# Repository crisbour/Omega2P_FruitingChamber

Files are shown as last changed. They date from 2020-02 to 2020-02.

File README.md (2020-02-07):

# Omega2P_FruitingChamber
Code for Omega2+ to control humidity, temperature, air flow and lights for an automated fruiting chamber to grow mushrooms.

Sensors:
- 2x D18B20 Temperature 1-Wire
- GY-BME280  Humidity + Temperature I<sup>2</sup>C

Humidifier:
- Mist Maker 24V
- 2x Pressure Optimized Arctic fans in series to double pressure

Output inside FC:
- 2x 10W LED 6000K Lamps
- 5v Fan to homogenize temperature and humidity withi the FC

User Interface:
- 16x2 LCD display with I<sup>2</sup>C interface
- Rotary Encoder + RGB LED with I<sup>2</sup>C interface

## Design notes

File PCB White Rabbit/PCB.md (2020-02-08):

Here is the circuit that shows what is hooked to Omega2+ and the PCB layout that has been manufactured.
The circuit and PCB have been designed in Eagle Autodesk.

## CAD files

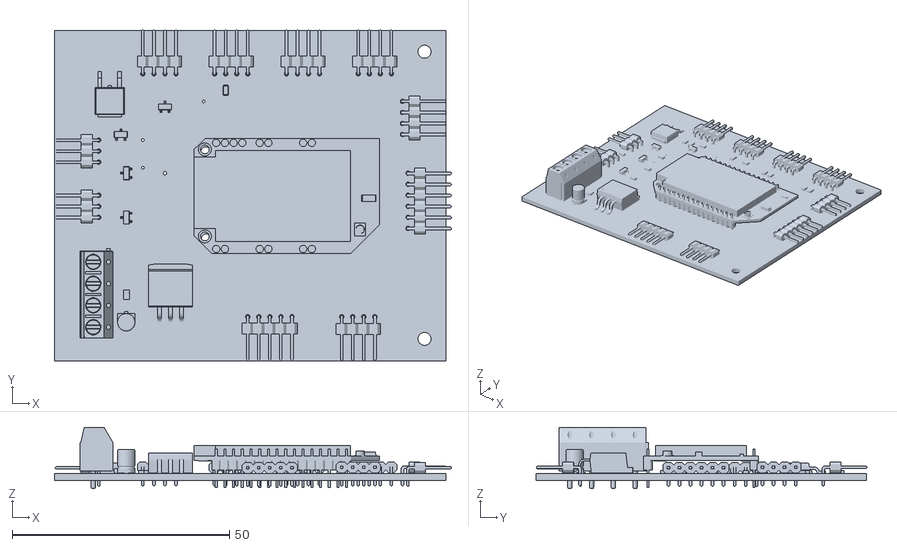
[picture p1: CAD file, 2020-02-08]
PCB White Rabbit/WhiteRabbit v8.stl
91.3 x 76.1 x 14.1

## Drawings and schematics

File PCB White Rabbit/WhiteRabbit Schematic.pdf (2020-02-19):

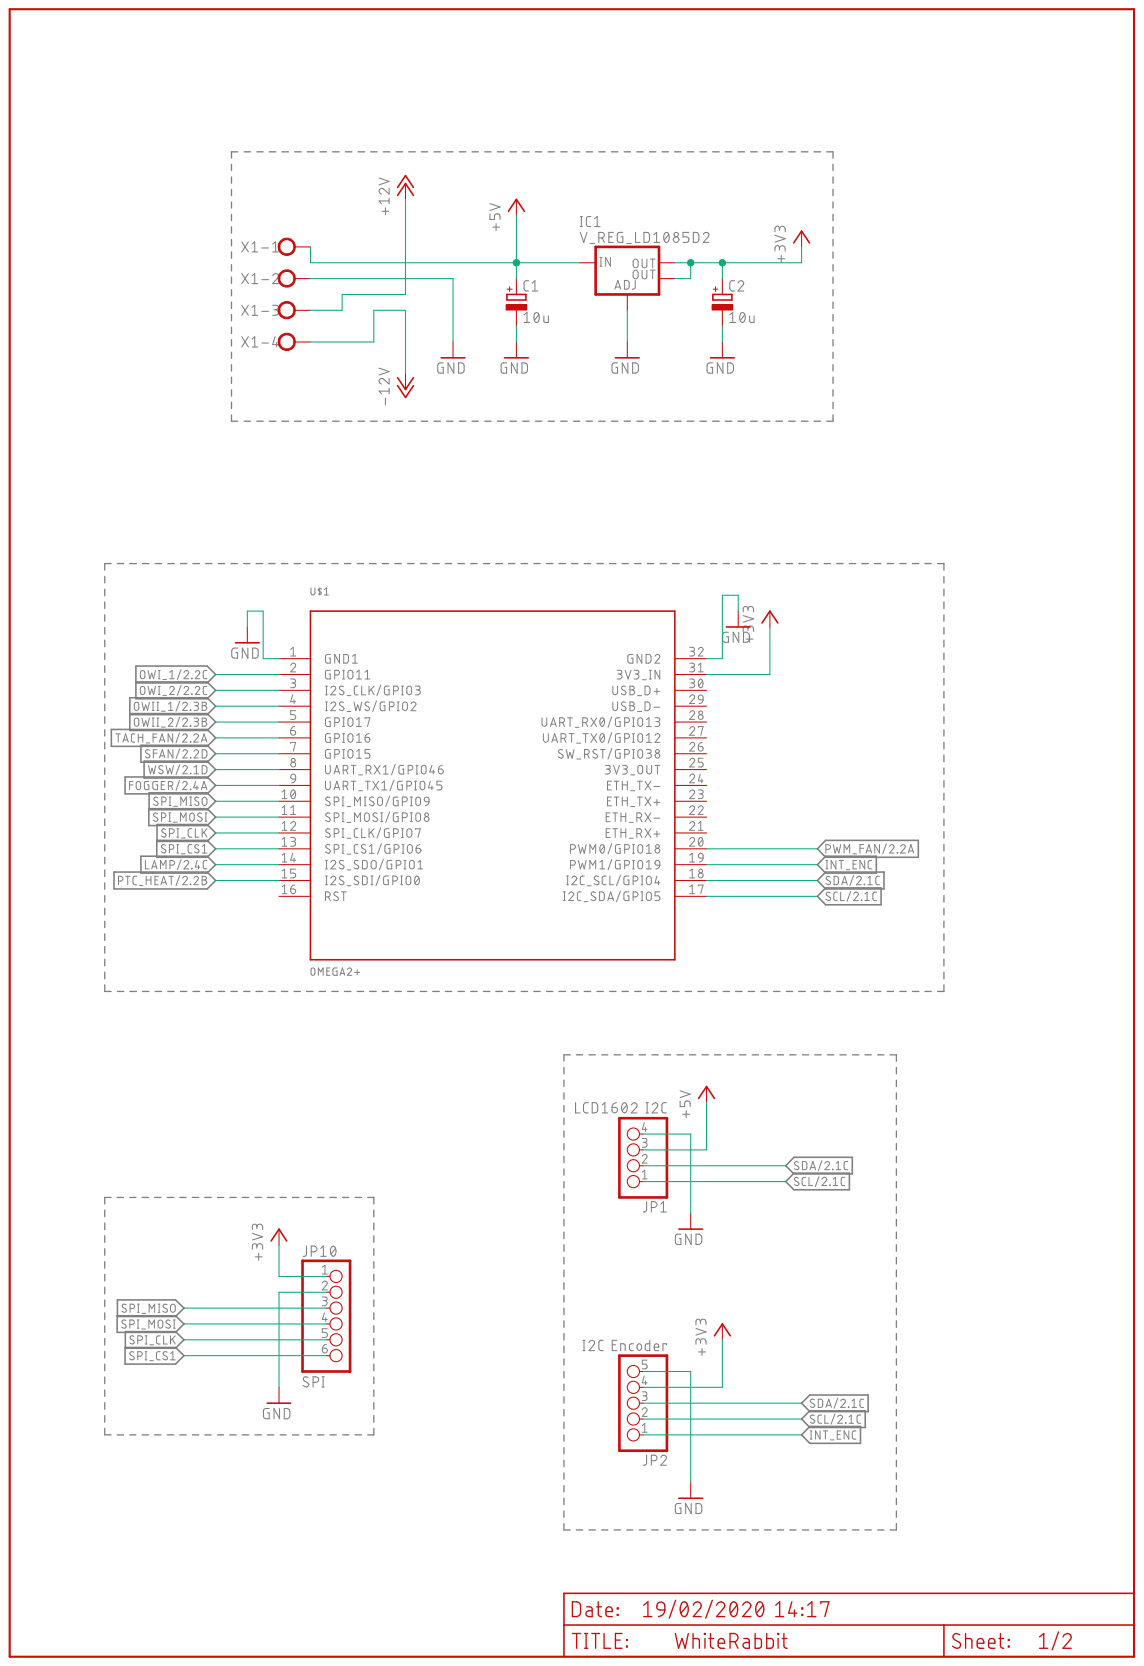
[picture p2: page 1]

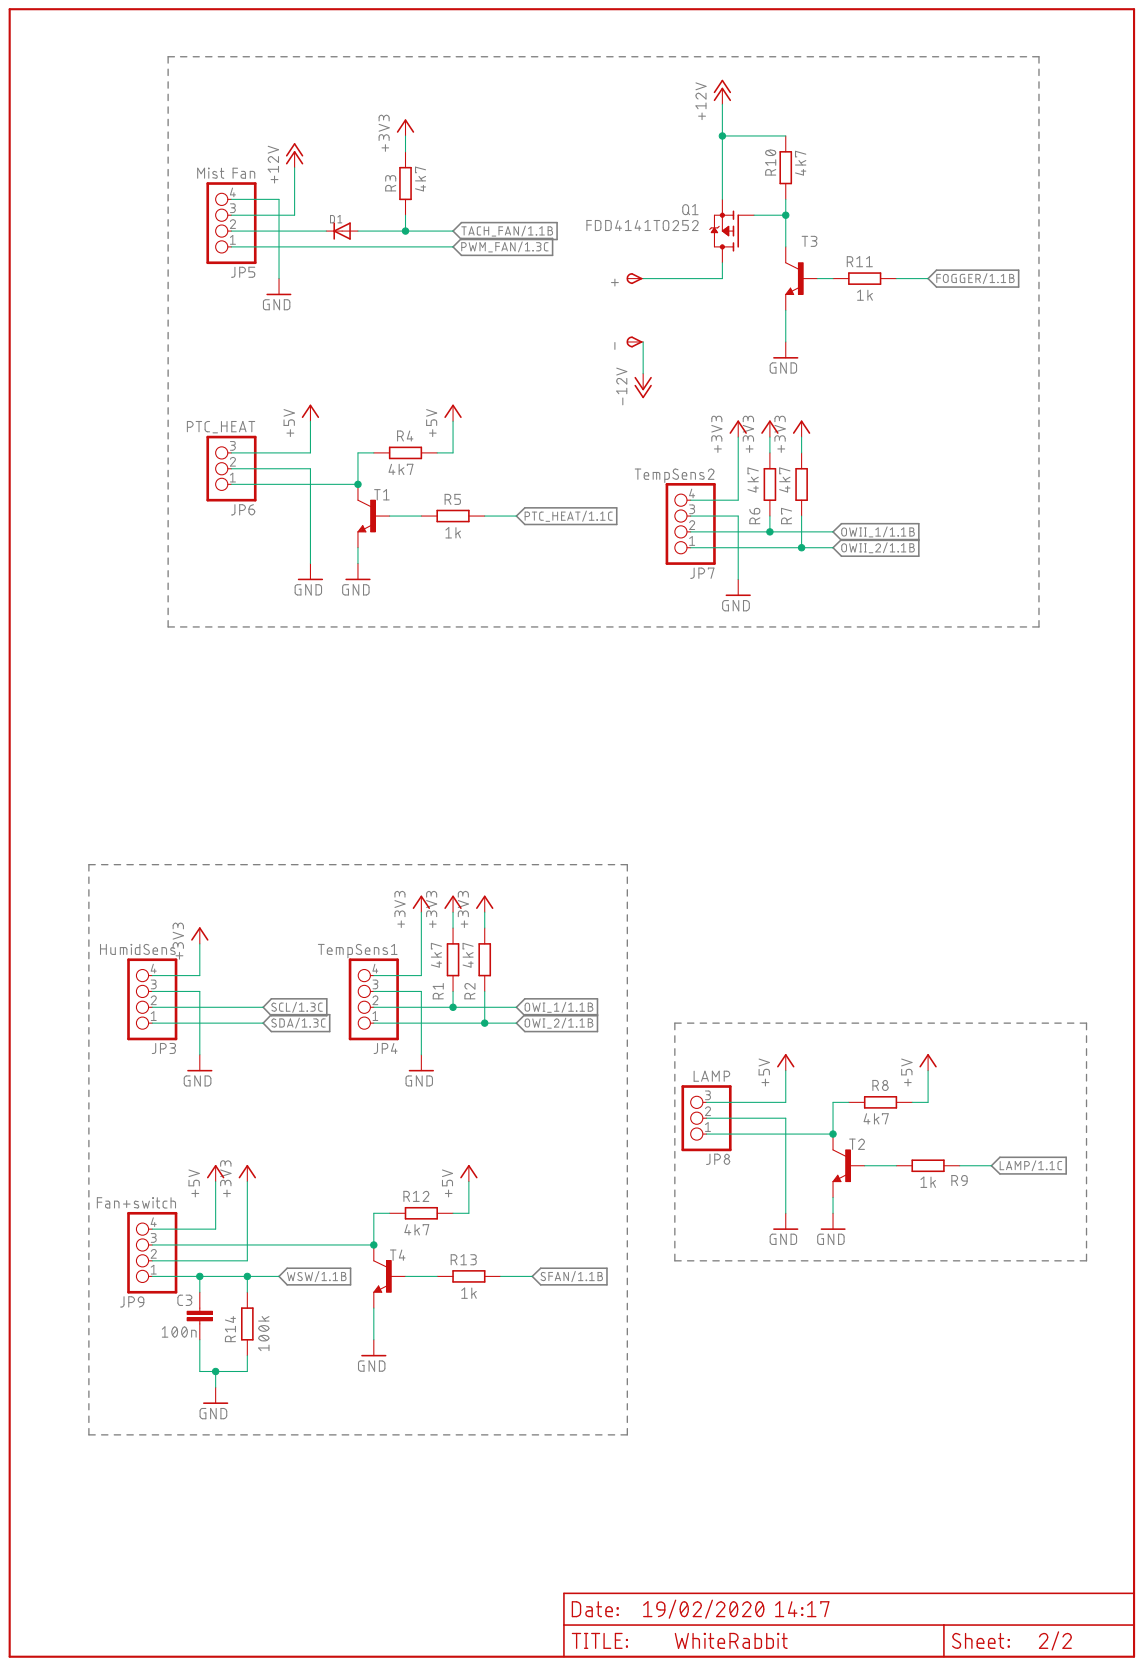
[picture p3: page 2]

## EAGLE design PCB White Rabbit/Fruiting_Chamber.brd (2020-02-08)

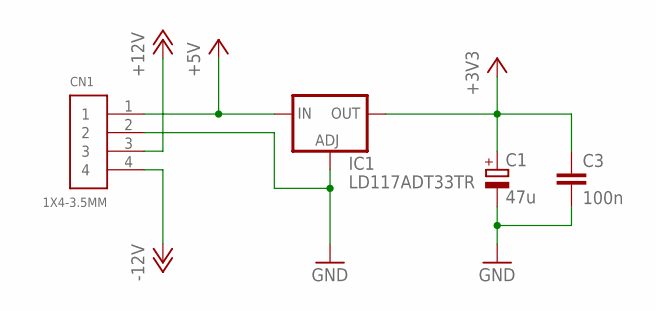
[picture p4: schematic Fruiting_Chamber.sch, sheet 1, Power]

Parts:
C1: 47u; E2,5-6
C3: 100n; C0603
CN1: 1X4-3.5MM; 1X04-3.5MM
IC1: LD117ADT33TR; DPACK

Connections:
+3V3: C1.+, C3.1, IC1.4 (OUT); also elsewhere on the board
+5V: CN1.1, IC1.3 (IN); also elsewhere on the board
+12V: CN1.3; also elsewhere on the board
-12V: CN1.4; also elsewhere on the board
GND: C1.-, C3.2, CN1.2, IC1.1 (ADJ); also elsewhere on the board

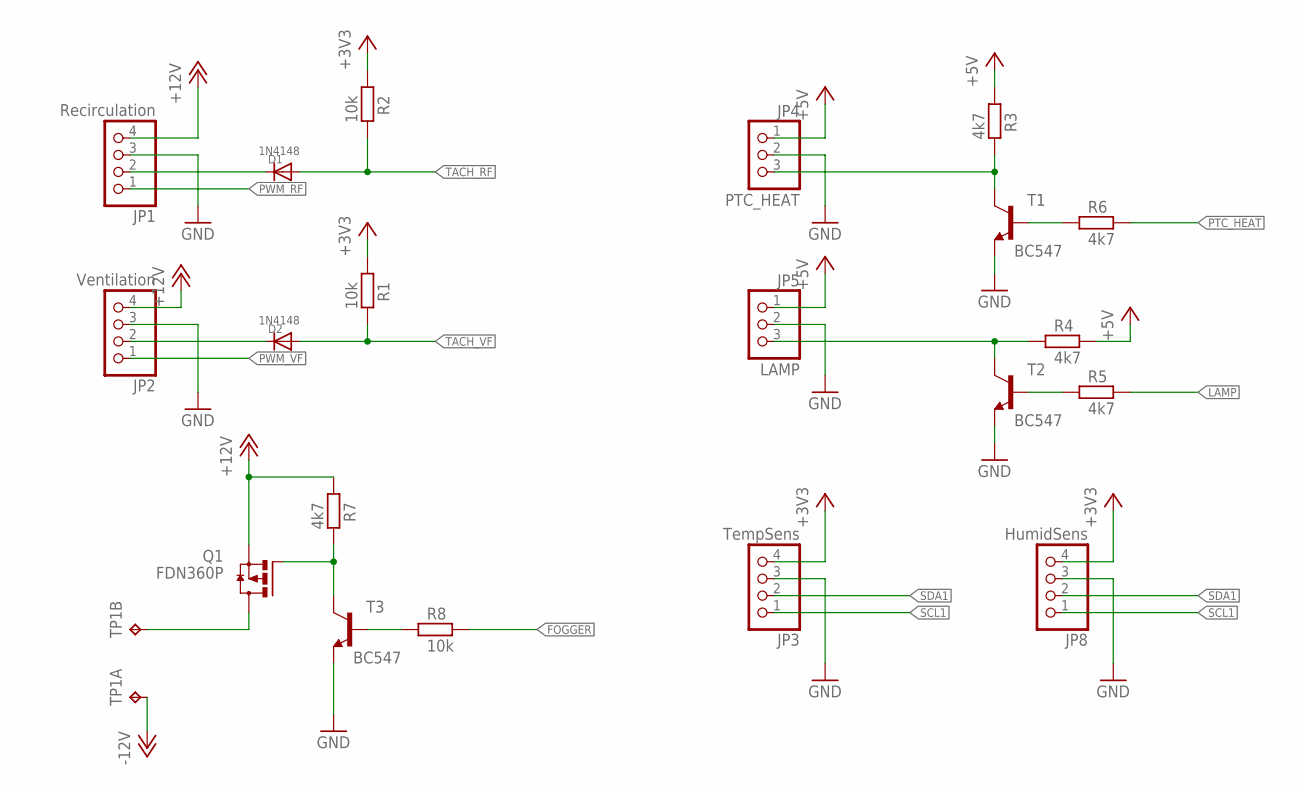
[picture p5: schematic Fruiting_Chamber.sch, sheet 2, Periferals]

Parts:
D1, D2: 1N4148; DO-1N4148
JP1: Recirculation; 1X04/90
JP2: Ventilation; 1X04/90
JP3: TempSens; 1X04/90
JP4: PTC_HEAT; 1X03/90
JP5: LAMP; 1X03/90
JP8: HumidSens; 1X04/90
Q1: FDN360P; SUPER-SOT3
R1, R2, R8: 10k; R0805
R3, R4, R5, R6, R7: 4k7; R0805
T1, T2, T3: BC547; TO92
TP1: TP2P2-38-20; P2-38-20

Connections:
+3V3: JP3.4, JP8.4, R1.1, R2.1; also elsewhere on the board
+5V: JP4.1, JP5.1, R3.1, R4.2; also elsewhere on the board
+12V: JP1.4, JP2.4, Q1.2 (S), R7.1; also elsewhere on the board
-12V: TP1.TP-1; also elsewhere on the board
FOGGER: R8.2; also elsewhere on the board
GND: JP1.3, JP2.3, JP3.3, JP4.2, JP5.2, JP8.3, T1.1 (E), T2.1 (E), T3.1 (E); also elsewhere on the board
LAMP: R5.2; also elsewhere on the board
unnamed: D1.C, JP1.2
unnamed: JP5.3, R4.1, T2.3 (C)
unnamed: D2.C, JP2.2
unnamed: JP4.3, R3.2, T1.3 (C)
unnamed: R6.1, T1.2 (B)
unnamed: R5.1, T2.2 (B)
unnamed: Q1.3 (D), TP1.TP-2
unnamed: Q1.1 (G), R7.2, T3.3 (C)
unnamed: R8.1, T3.2 (B)
PTC_HEAT: R6.2; also elsewhere on the board
PWM_RF: JP1.1; also elsewhere on the board
PWM_VF: JP2.1; also elsewhere on the board
SCL1: JP3.1, JP8.1; also elsewhere on the board
SDA1: JP3.2, JP8.2; also elsewhere on the board
TACH_RF: D1.A, R2.2; also elsewhere on the board
TACH_VF: D2.A, R1.2; also elsewhere on the board

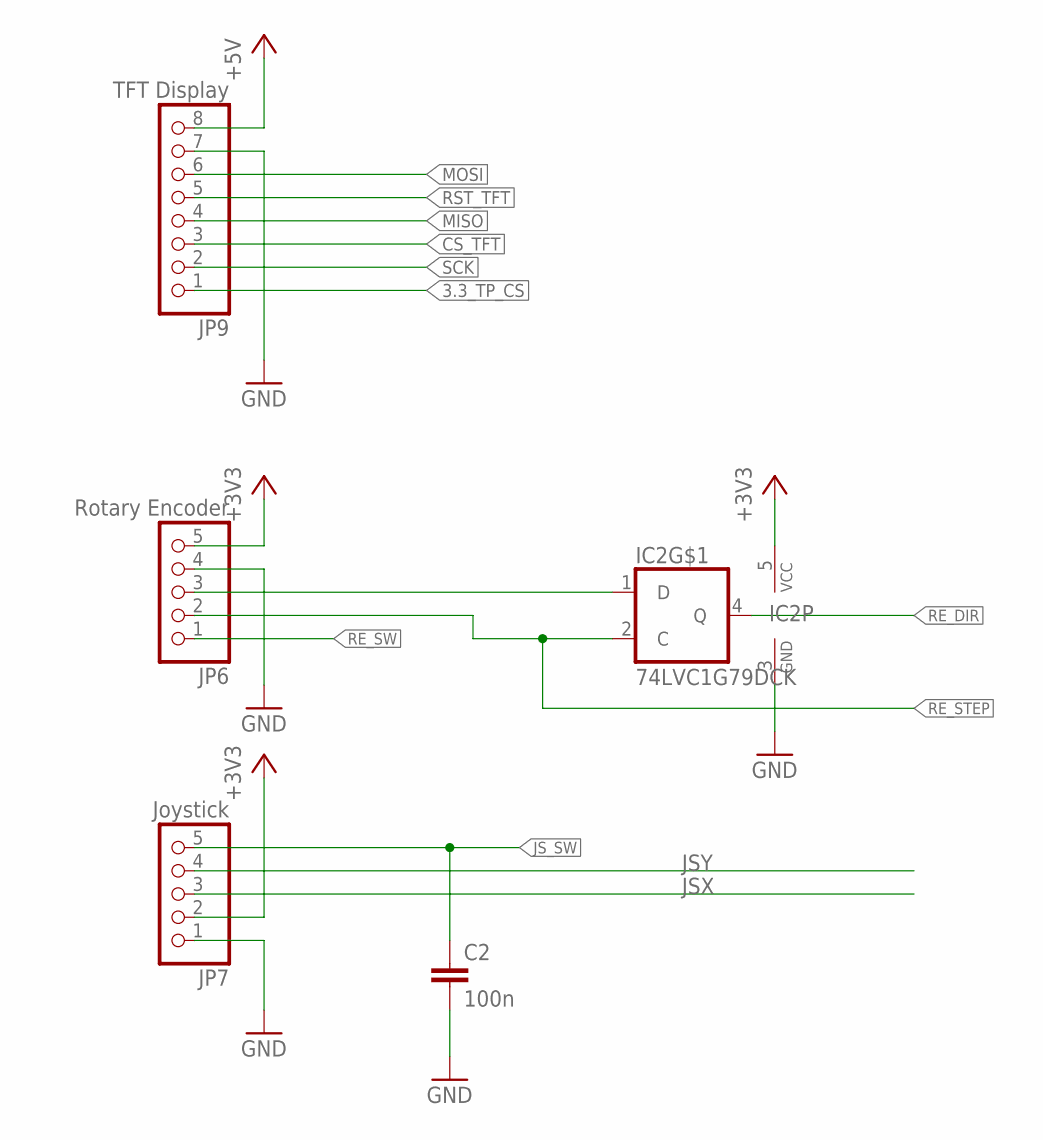
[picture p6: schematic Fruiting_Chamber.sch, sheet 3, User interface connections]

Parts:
C2: 100n; C0603
IC2: 74LVC1G79DCK; SC70-5
JP6: Rotary Encoder; 1X05/90
JP7: Joystick; 1X05/90
JP9: TFT Display; 1X08/90

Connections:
3.3_TP_CS: JP9.1; also elsewhere on the board
+3V3: IC2.5 (VCC), JP6.5, JP7.2; also elsewhere on the board
+5V: JP9.8; also elsewhere on the board
CS_TFT: JP9.3; also elsewhere on the board
GND: C2.2, IC2.3 (GND), JP6.4, JP7.1, JP9.7; also elsewhere on the board
JSX: JP7.3
JSY: JP7.4
JS_SW: C2.1, JP7.5
MISO: JP9.4; also elsewhere on the board
MOSI: JP9.6; also elsewhere on the board
unnamed: IC2.1 (D), JP6.3
RE_DIR: IC2.4 (Q); also elsewhere on the board
RE_STEP: IC2.2 (C), JP6.2; also elsewhere on the board
RE_SW: JP6.1; also elsewhere on the board
RST_TFT: JP9.5; also elsewhere on the board
SCK: JP9.2; also elsewhere on the board

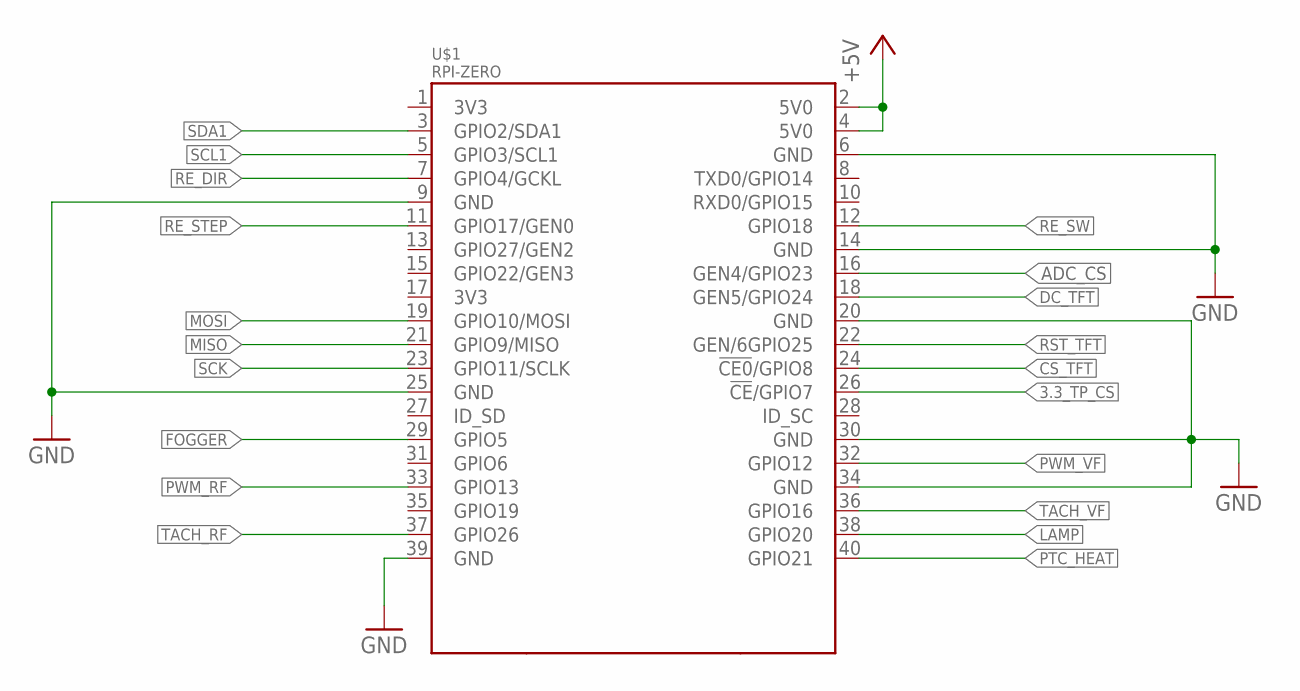
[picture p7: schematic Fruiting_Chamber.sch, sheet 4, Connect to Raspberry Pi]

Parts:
U$1: RPI-ZERO; RASPBERRYPI_BASTELSTUBE_V13_RASPI_BOARD_B+_FULL

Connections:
3.3_TP_CS: U$1.26 (!CE!/GPIO7); also elsewhere on the board
+5V: U$1.2 (5V0), U$1.4 (5V0); also elsewhere on the board
ADC_CS: U$1.16 (GEN4/GPIO23)
CS_TFT: U$1.24 (!CE0!/GPIO8); also elsewhere on the board
DC_TFT: U$1.18 (GEN5/GPIO24)
FOGGER: U$1.29 (GPIO5); also elsewhere on the board
GND: U$1.6 (GND), U$1.9 (GND), U$1.14 (GND), U$1.20 (GND), U$1.25 (GND), U$1.30 (GND), U$1.34 (GND), U$1.39 (GND); also elsewhere on the board
LAMP: U$1.38 (GPIO20); also elsewhere on the board
MISO: U$1.21 (GPIO9/MISO); also elsewhere on the board
MOSI: U$1.19 (GPIO10/MOSI); also elsewhere on the board
PTC_HEAT: U$1.40 (GPIO21); also elsewhere on the board
PWM_RF: U$1.33 (GPIO13); also elsewhere on the board
PWM_VF: U$1.32 (GPIO12); also elsewhere on the board
RE_DIR: U$1.7 (GPIO4/GCKL); also elsewhere on the board
RE_STEP: U$1.11 (GPIO17/GEN0); also elsewhere on the board
RE_SW: U$1.12 (GPIO18); also elsewhere on the board
RST_TFT: U$1.22 (GEN/6GPIO25); also elsewhere on the board
SCK: U$1.23 (GPIO11/SCLK); also elsewhere on the board
SCL1: U$1.5 (GPIO3/SCL1); also elsewhere on the board
SDA1: U$1.3 (GPIO2/SDA1); also elsewhere on the board
TACH_RF: U$1.37 (GPIO26); also elsewhere on the board
TACH_VF: U$1.36 (GPIO16); also elsewhere on the board

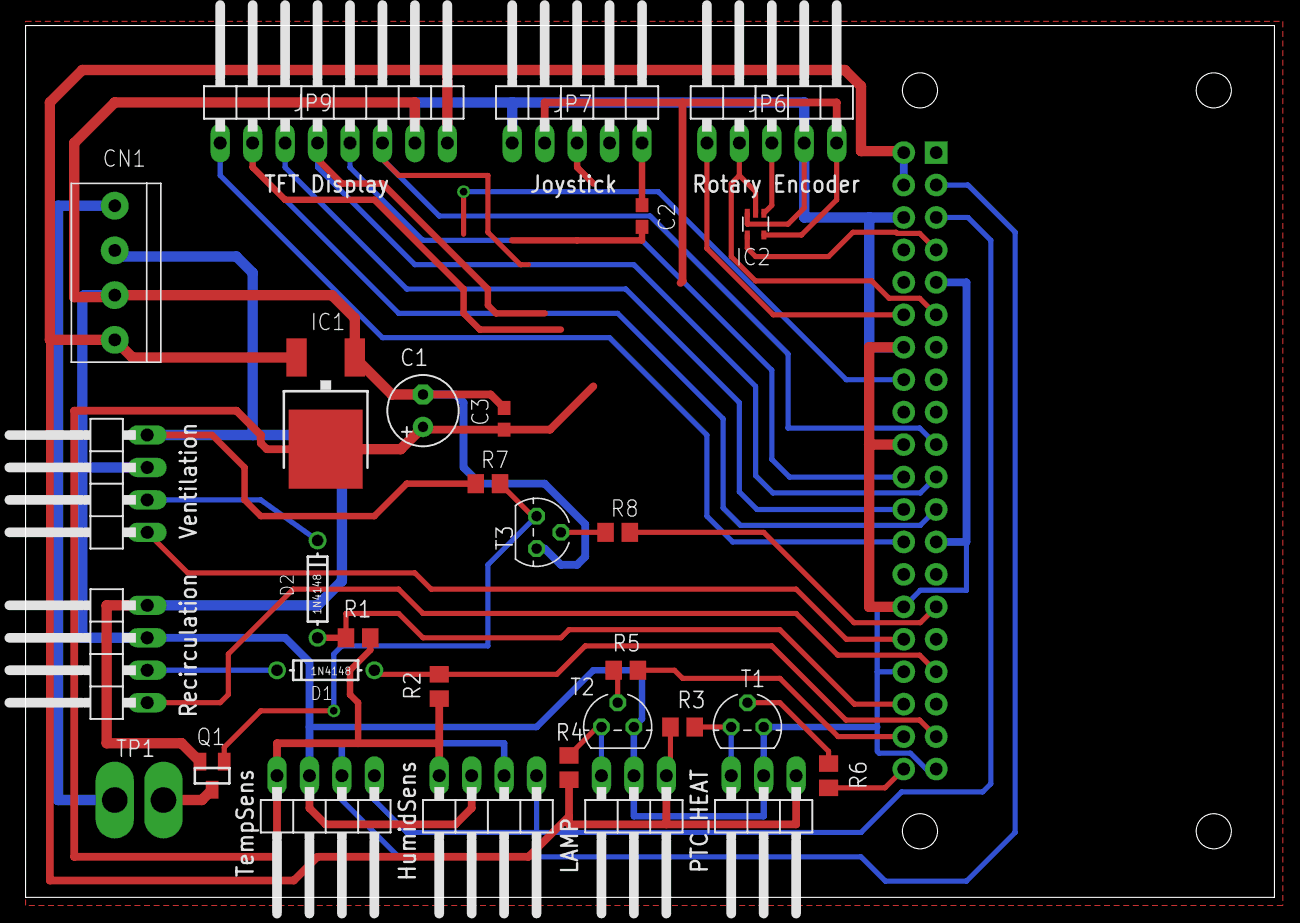
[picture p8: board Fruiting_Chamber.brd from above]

Board: 2 copper layers, 97.8 x 68.2 mm, 31 parts (1 on the bottom side), 34 nets.

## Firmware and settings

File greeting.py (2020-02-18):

#! /usr/bin/python

# Importing package
import time
import os
import onionGpio
from temperatureSensor import TemperatureSensor
import oneWire
from datetime import datetime

dayStart=9; dayFinish=21;

oneWireGpio=11
def strTemp(sensor):
	value=sensor.readValue()
	print("T= "+str(value) +" C")

#I/O and PWM set up
os.system('omega2-ctrl gpiomux set uart1 gpio')
os.system('omega2-ctrl gpiomux set pwm0 pwm')
LampPin=1; FoggerPin=45; StirPin=15;
LampObj=onionGpio.OnionGpio(LampPin)
StirObj=onionGpio.OnionGpio(StirPin)
FoggerObj=onionGpio.OnionGpio(FoggerPin) 

#1-Wire Init
if not oneWire.setupOneWire(str(oneWireGpio)):
	print("Kernel mdule could not be inserted. Try again!")
sensorAddress=oneWire.scanOneAddress()
sensor=TemperatureSensor("oneWire",{"address":sensorAddress,"gpio":oneWireGpio})
if not sensor.ready:
	print("Sensore was not set up correctly.")

os.system('onion pwm 0 0 1000')
LampObj.setOutputDirection(0)
FoggerObj.setOutputDirection(0)
StirObj.setOutputDirection(1)

foggSet=True

now=datetime.now()
if(dayStart<=now.hour<dayFinish):
	dayBool=False
else:
	dayBool=True

print("Current time: "+ now.strftime("%c"));

while True:
	now=datetime.now() 

	if(dayStart<=now.hour<dayFinish):
		LampObj.setOutputDirection(0)	#Turn on the lamp
		if(not dayBool):
			print("It's day time!");
			dayBool=True
	else:
		LampObj.setOutputDirection(1)	#Turn off the lamp
		if(dayBool):
			print("It's night time!");
			dayBool=False

	if 45<=now.minute<50 and (not foggSet) :
		FoggerObj.setOutputDirection(1)
		StirObj.setOutputDirection(1)
		os.system('onion pwm 0 100 1000')
		print('Misting')
		foggSet=True
	if not(45<=now.minute<50) and foggSet :
		time.sleep(30)
		FoggerObj.setOutputDirection(0)
		StirObj.setOutputDirection(0)
		os.system('onion pwm 0 0 1000')
		print('Pause')
		foggSet=False
	
	if(now.minute%10==0 and now.second==0):
		strTemp(sensor)				#Display temperature inside the FC

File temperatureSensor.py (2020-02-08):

from oneWire import OneWire

# main class definition
class TemperatureSensor:
    def __init__(self, interface, args):
        self.supportedInterfaces = ["oneWire"]
        self.interface = interface
        self.ready = False

        # if specified interface not supported
        if self.interface not in self.supportedInterfaces:
            print "Unsupported interface."
            self.listInterfaces()
            return

        # set up a driver based on the interface type
        # you can extend this class by adding more drivers! (eg. serial, I2C, etc)
        if self.interface == "oneWire":
            self.driver = OneWire(args.get("address"), args.get("gpio", None))
            # signal ready status
            self.ready = self.driver.setupComplete
            # match the return value to
            self.readValue = self.__readOneWire;

    def listInterfaces(self):
        print "The supported interfaces are:"
        for interface in self.supportedInterfaces:
            print interface

    # read one-wire devices
    def __readOneWire(self):
        # device typically prints 2 lines, the 2nd line has the temperature sensor at the end
        # eg. a6 01 4b 46 7f ff 0c 10 5c t=26375
        rawValue = self.driver.readDevice()

        # grab the 2nd line, then read the last entry in the line, then get everything after the "=" sign
        value = rawValue[1].split()[-1].split("=")[1]

        # convert value from string to number
        value = int(value)

        # DS18B20 outputs in 1/1000ths of a degree C, so convert to standard units
        value /= 1000.0
        return value

    # add more __read() functions for different interface types later!

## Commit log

2020-02-08 Print transition between day and night
2020-02-08 PCB folder
2020-02-08 Eagle files of White Rabbit
    [Fruiting_Chamber.brd, Fruiting_Chamber.sch]
2020-02-08 3D model of White Rabbit PCB
    [WhiteRabbit v8.stl]
2020-02-18 PDF schematic
2020-02-19 1k ohm resistors on transistors base
